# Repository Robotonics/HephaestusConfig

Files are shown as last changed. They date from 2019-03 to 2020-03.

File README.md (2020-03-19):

# HephaestusConfig

The contents of this repo:

 * content of SD card that goes into my Duet 2 WiFi circuit board
  * printer firmware configuration files
  * homing macros
  * filament configurations
  * other useful files
 * Cura files that add the printer to the Cura slicer
  * printer configuration
  * nozzle configurations
  * 3D model of print bed

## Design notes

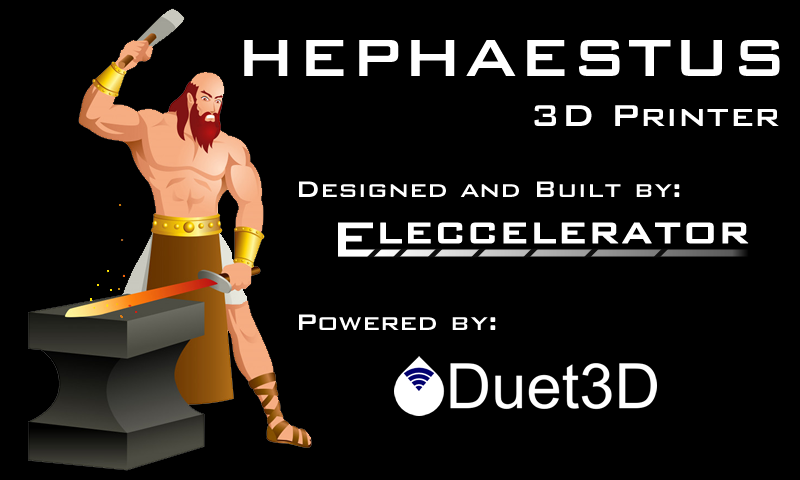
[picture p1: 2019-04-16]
duet/paneldue/hephaestus.fw.png

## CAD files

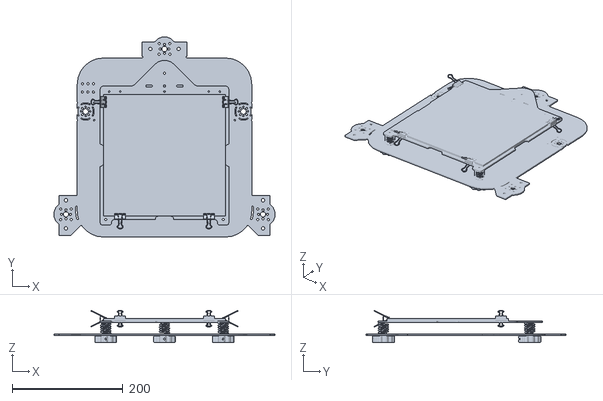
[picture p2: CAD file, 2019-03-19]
cura/resources/meshes/Hephaestus_platform.STL
398.8 x 360.9 x 58.0

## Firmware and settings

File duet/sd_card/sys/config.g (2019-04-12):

; Configuration file for Duet WiFi
; executed by the firmware on start-up

; General preferences
G90                                      ; Send absolute coordinates...
M83                                      ; ...but relative extruder moves

; Network
M550 P"Hephaestus"                       ; Set machine name
M551 P""                                 ; Set password
M552 S1                                  ; Enable network
M586 P0 S1                               ; Enable HTTP
M586 P1 S1                               ; Enable FTP
M586 P2 S0                               ; Disable Telnet
;M21 P0                                  ; Mount SD internal card

; Fake U Axis
M584 X0 Y1 Z2 E3 U3 P4                   ; Create U axis and assign to drive 3 (extruder)
                                         ; This is done to enable the external button to become a "stop extrude" button on the extruder
                                         ; Suggested as a workaround by dc42 (22 Dec 2018, 08:35) https://forum.duet3d.com/post/74169
M584 P3                                  ; This hides the U axis from the GUI, it needs to be unhidden later

; Drives
M98 P0:/sys/steppersettings.g

; Axis Limits
M208 X0 Y0 Z0 S1                         ; Set axis minima
M208 X190 Y170 Z288 S0                   ; Set axis maxima
; printer measurement to be done later

; Endstops
M574 X1 Y1 S3                            ; Set X and Y endstops controlled by motor load detection

; Bed Heater
M305 P0 T100000 B3950 R4700              ; Set thermistor + ADC parameters for heater 0
; Keenovo standard silicone heater pad, NTC 100K thermistor, Beta 25/50 3950K-1%
; Duet WiFi uses 4.7Kohm resistor for divider
M143 H0 S120                             ; Set temperature limit for heater 0
M307 A202.5 C368.4 D3.7 B0 S1.0 V24.2    ; Tuned parameters

; Nozzle Heater
M305 P1 X200                             ; Configure PT100 for heater 1
M143 H1 S300                             ; Set temperature limit for heater 1
M307 A834.7 C226.9 D3.4 B0 S1.0 V24.2     ; Tuned parameters

; Fans
M106 P0 S1 I0 F500 H-1                   ; Set fan 0 value, PWM signal inversion and frequency. Thermostatic control is turned off
M106 P0 S0                               ; Set fan 0 off
M106 P1 I-1                              ; disable fan 1, allow use as GPIO
M106 P2 I-1                              ; disable fan 2, allow use as GPIO

; Tools
M563 P0 D0 H1                            ; Define tool 0
G10 P0 X0 Y0 Z0                          ; Set tool 0 axis offsets
;G10 P0 R0 S200                           ; Set initial tool 0 active and standby temperatures
                                         ; Do not set tool initial temperature, tpostn will recall settings for previously used filament

G10 P0 R0 S0                             ; Set tool temperature to 0 so we can call T0 without a safety hazard
T0 P0                                    ; For some reason, calling M703 without T0 first will fail, quite annoying

; Volumetric Extrusion
;M200 D2.85                               ; Set filament diameter
; nozzle size needs to be set
; volumetric extrusion might not be supported yet

M18                                      ; Disable all stepper motors



; Automatic saving after power loss is not enabled

; Custom settings are not configured

; M501 not yet ysed

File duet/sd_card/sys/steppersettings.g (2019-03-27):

M569 P0 S0                               ; Drive 0 (X) goes backwards
M569 P1 S0                               ; Drive 1 (Y) goes backwards
M569 P2 S0                               ; Drive 2 (Z) goes backwards
M569 P3 S0                               ; Drive 3 (E) goes backwards

M350 X16 Y16 I1                          ; Configure microstepping with interpolation
M350 Z16 I1                              ; Configure microstepping with interpolation
;M350 E1 I1                               ; Configure microstepping with interpolation
;M350 U1 I1                               ; Configure microstepping with interpolation
M350 E16 I1                              ; Configure microstepping with interpolation
M350 U16 I1                              ; Configure microstepping with interpolation

M92 X80.00 Y80.00                        ; Set steps per mm
; 2mm belt pitch
; 20 teeth pulley
; 1 full rotation, 200 steps = 40mm travel
; 1 full step = 0.2mm of travel
; 5 full steps per mm
; 1/16 microstepping
; 5 * 16 = 80

M92 Z400.00                              ; Set steps per mm
; 40 um per full step
; 1000/40 = 25
; 25 * 16 = 400

; digging through Prusa i3 MK3 release firmware files
; 280 steps/mm with 1/32 microstepping (also see 560 steps/mm with 1/64 microstepping)
; rough estimate of gear diameter is between 7 and 8mm (Bondtech says their mini gears have estep = 140m, unknown microstepping, unknown deg/step)
; 280 / 32 = 8.75 full steps per mm, 200/8.75 = 22.86mm circumference of gear, meaning 7.28 effective gear diameter
; our worm gear drive has a 40x gear reduction
; disable microstepping
; 8.75 * 40 = 350
;M92 E350.00                              ; Set steps per mm
;M92 U350.00                              ; Set steps per mm
M92 E5600.00                             ; Set steps per mm (with microstepping)
M92 U5600.00                             ; Set steps per mm (with microstepping)

; acceleration and jerk for X and Y are set in the following macro
M98 P0:/sys/stepperacceljerk.g

M566 E120.00                             ; Set maximum instantaneous speed changes (mm/min)
M566 U120.00                             ; Set maximum instantaneous speed changes (mm/min)

M203 X30000.00 Y30000.00                 ; Set maximum speeds (mm/min)
M203 Z1000.00                            ; Set maximum speeds (mm/min)
M203 E800.00                             ; Set maximum speeds (mm/min)
M203 U800.00 I15.00                      ; Set maximum speeds (mm/min), and minimum

M201 E250.00                             ; Set accelerations (mm/s^2)
M201 U250.00                             ; Set accelerations (mm/s^2)

M906 X1600.00 Y1600.00 I30               ; Set motor currents (mA) and motor idle factor in percent
M906 Z800.00 I30                         ; Set motor currents (mA) and motor idle factor in percent
M906 E1800.00 I30                        ; Set motor currents (mA) and motor idle factor in percent
M906 U1800.00 I30                        ; Set motor currents (mA) and motor idle factor in percent

M84 S30                                  ; Set idle timeout

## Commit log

2019-03-19 cura profile uploaded
    [Hephaestus_platform.STL]
2019-03-19 upload gcode config and macros
    [bed.g, bed_manual_level.g, bed_raise.g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]
2019-03-19 fixed the Z dive causing Z to be considered home bug
    [homex.g]
2019-03-19 remove volumetric extrusion, removed padding, added minimum U feedrate
    [config.g, steppersettings.g]
2019-03-23 added filaments entry
    [config.g, load.g, unload.g]
2019-03-23 recall last used filament
    [config.g, filament_extract.g, filament_insert.g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]
2019-03-23 more filaments configured
    [config.g, load.g, unload.g]
2019-03-23 major homing tweaks, no more weird Z motor config swapping
    [homeall.g, homex.g, homey.g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]
2019-03-23 width of printer reduced
    [config.g]
2019-03-24 removal of non-microstepped Z config
    [raisebed.g, steppersettings.g, z_mode_rough.g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]
2019-03-24 fixed Y stall detect not working in homeall
    [homeall.g]
2019-03-24 cura nozzle settings version compatibility
2019-03-24 cura expects absolute extrusion mode in start script
    [endprint.g, startprint.g]
2019-03-24 remove Z probe configuration
    [config.g]
2019-03-24 filament config packaging tool
2019-03-24 bed leveling bug fixes
    [bed.g, bed_manual_level.g, preheat_prompt.g]
2019-03-24 adjust filament retraction settings
    [config.g]
2019-03-24 start/stop/insert script fixed for correct speeds and behaviour
    [endprint.g, filament_insert.g, startprint.g]
2019-03-25 disables tpost0 wait
    [tpost0.g]
2019-03-25 test prints
2019-03-27 sped up Z accel and jerk during print
    [homeall.g, homez.g, homingsteppersettings.g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]
2019-03-27 slowed down E speed during pause/resume
    [pause.g, resume.g]
2019-03-27 re-tuned nozzle heater params
    [config.g]
2019-03-27 pause and resume button trigger changes
    [endprint.g, pause.g, resume.g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]
2019-03-27 change direction of move to clear the start prime blob
    [startprint.g]
2019-03-27 ensure end of print dives the bed down first
    [endprint.g]
2019-04-01 wait for move to finish before dismissing prompt
    [filament_insert.g]
2019-04-01 filament extraction speed was too high, lowered it
    [filament_extract.g]
2019-04-01 added filament_recall.g
    [filament_recall.g]
2019-04-01 manual bed level script now homes Z as well
    [bed_manual_level.g]
2019-04-01 adjusted filament retraction for pause and resume
    [endprint.g, pause.g, resume.g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]
2019-04-04 new printer size due to new extruder design
    [config.g]
2019-04-05 PLA temperature lowered
    [config.g, load.g, unload.g]
2019-04-05 changed accel settings to reduce vibration
    [stepperacceljerk.g]
2019-04-05 attempt to improve tool select workflow
    [config.g, filament_extract.g, filament_insert.g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]
2019-04-12 slow down purge extrude moves, seems too fast
    [filament_insert.g, startprint.g]
2019-04-12 re-tuned nozzle heater
    [config.g]
2019-04-12 wider temperature tolerance for initialization scripts
    [filament_insert.g, startprint.g]
2019-04-12 renamed macro files for sorting
    [1_filament_extract.g, 1_filament_insert.g, 1_filament_recall.g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]
2019-04-12 re-sort macros
    [3_network_AP.g, 4_network_report.g, 5_network_connect.g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]
2019-04-12 fan on during print pre-heat
    [startprint.g]
2019-04-13 fixed missing macro after rename fiasco
    [startprint.g]
2019-04-13 still trying to fix the dive
    [endprint.g]
2019-04-13 improved print startup behaviour, bed now always active, fan check fixed
    [raisebed.g, startprint.g]
2019-04-14 fixed bed level mistake from renaming macros
    [8_bed_manual_level.g, bed.g, bed_manual_level.g]
2019-04-16 better estimates for print time, by adding in accel/jerk data into machine defs
2019-04-23 filament extract wider temperature tolerance
    [filament_extract.g]
